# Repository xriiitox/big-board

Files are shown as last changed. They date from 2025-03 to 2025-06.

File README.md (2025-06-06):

# big-board

I wanted to make this keyboard to gain KiCAD experience and work on a larger project that included more difficult CAD.  
This was the first large-scale PCB I've worked on.  
The routing was very difficult, and it forced me to learn how to use vias correctly lol  

Personally, I don't really need much from a keyboard, so I tried to keep it simple with a minimalist design:
* No RGB
* No OLED Display
* No Rotary Encoders

Images: 

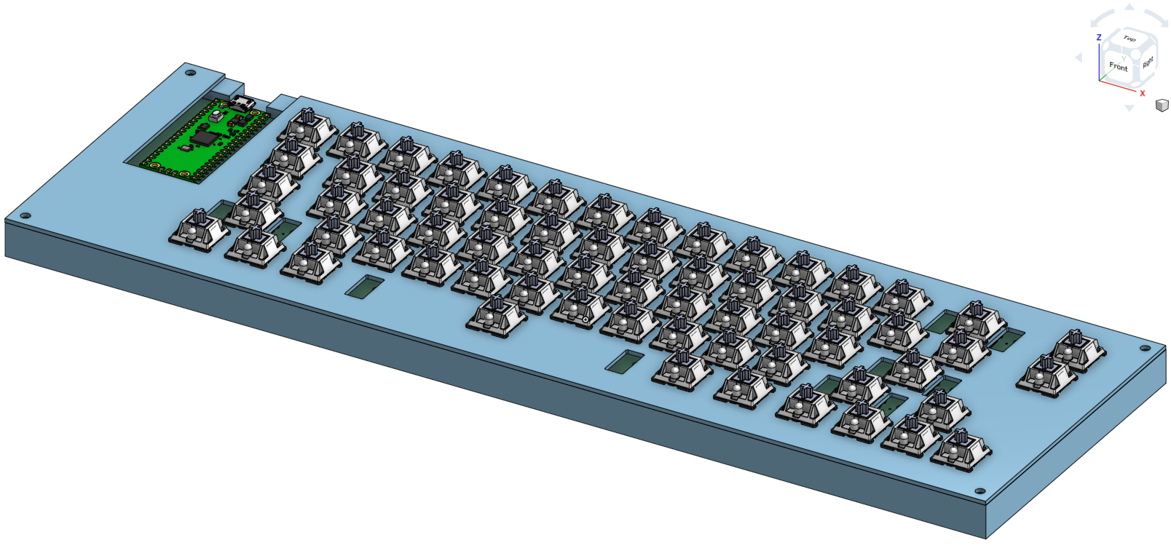
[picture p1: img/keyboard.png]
keyboard

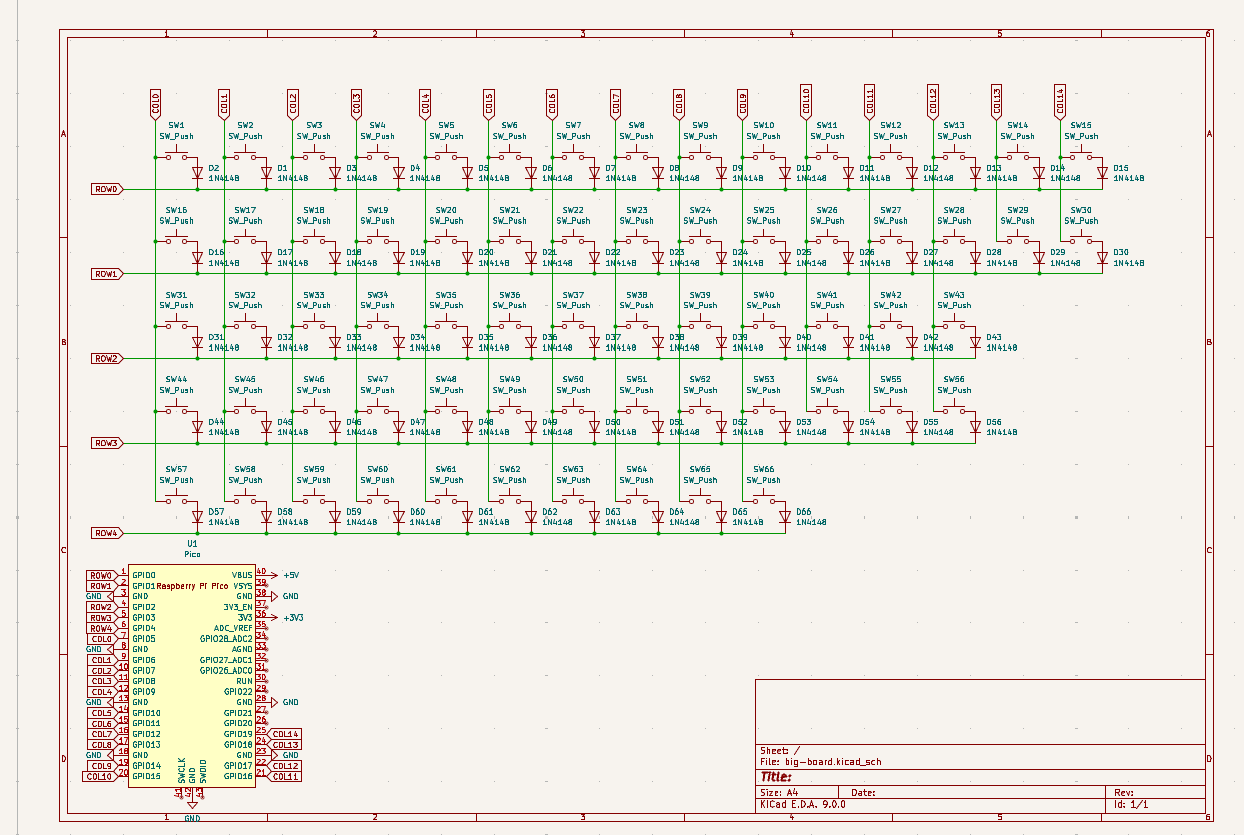
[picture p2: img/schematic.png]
schematic

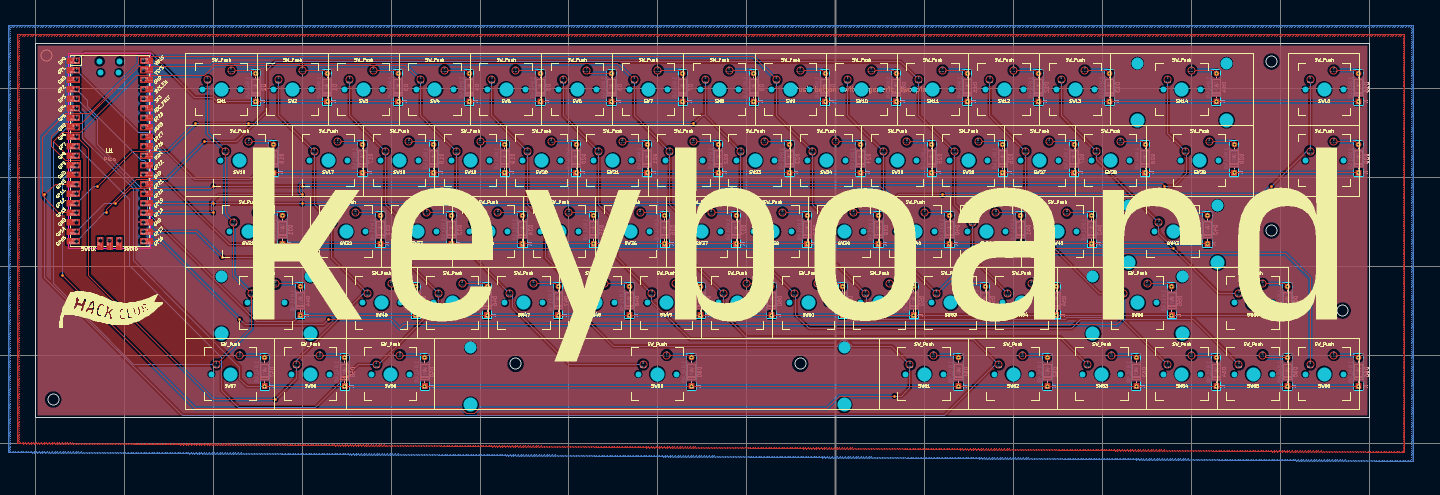
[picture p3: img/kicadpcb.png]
pcb


BOM:  
| Item | Quantity | $/item | Total (inc. shipping) | Link |
| --- | --- | --- | --- | ---- |
| 1N4148 | 70 | 0.0292 | ~$10.50 | https://www.digikey.com/en/products/detail/onsemi/1N4148/458603 |
| Switches | 80 | 2.30 | ~$23.40 | https://milktooth.com/products/switches/milky-yellow-pro |
| Keycaps  | 1 | 0.99 | ~$1.06  | https://www.aliexpress.us/item/3256807135386098.html  |
| Stabs | 1 set | 16.99  | $16.99 | https://www.amazon.com/DUROCK-Stabilizers-Stabilizer-Pre-Clipped-Mechanical/dp/B0B2RTQ1C2 |
| M3 Screws| 1 box | 9.99 | $9.99 | https://www.amazon.com/Assortment-Stainless-Replacement-Machine-Fastener/dp/B0BMQFHDBH |
| Orpheus Pico | 1 | 0.00 | 0.00 | N/A

PCB:
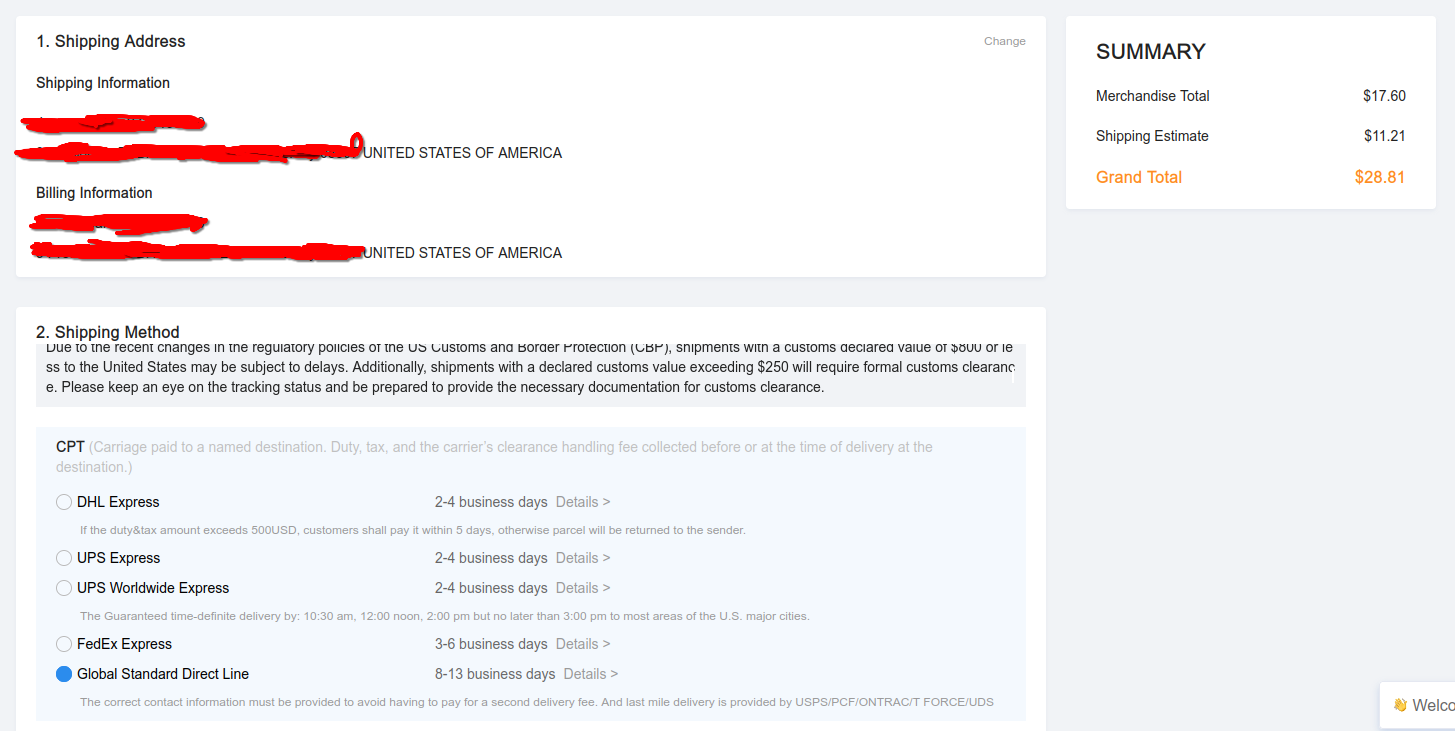
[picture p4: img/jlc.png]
jlcpcb


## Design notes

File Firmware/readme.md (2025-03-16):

# big_board

big_board

*A short description of the keyboard/project*

* Keyboard Maintainer: [Josh Baron](https://github.com/xriiitox)
* Hardware Supported: *The PCBs, controllers supported*
* Hardware Availability: *Links to where you can find this hardware*

Make example for this keyboard (after setting up your build environment):

    make big_board:default

Flashing example for this keyboard:

    make big_board:default:flash

See the [build environment setup](https://docs.qmk.fm/#/getting_started_build_tools) and the [make instructions](https://docs.qmk.fm/#/getting_started_make_guide) for more information. Brand new to QMK? Start with our [Complete Newbs Guide](https://docs.qmk.fm/#/newbs).

## Bootloader

Enter the bootloader in 3 ways:

* **Bootmagic reset**: Hold down the key at (0,0) in the matrix (usually the top left key or Escape) and plug in the keyboard
* **Physical reset button**: Briefly press the button on the back of the PCB - some may have pads you must short instead
* **Keycode in layout**: Press the key mapped to `QK_BOOT` if it is available

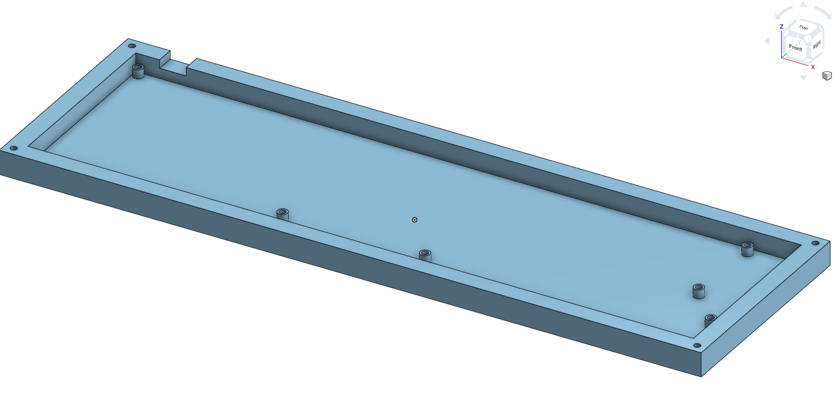
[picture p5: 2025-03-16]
img/lower-case.png

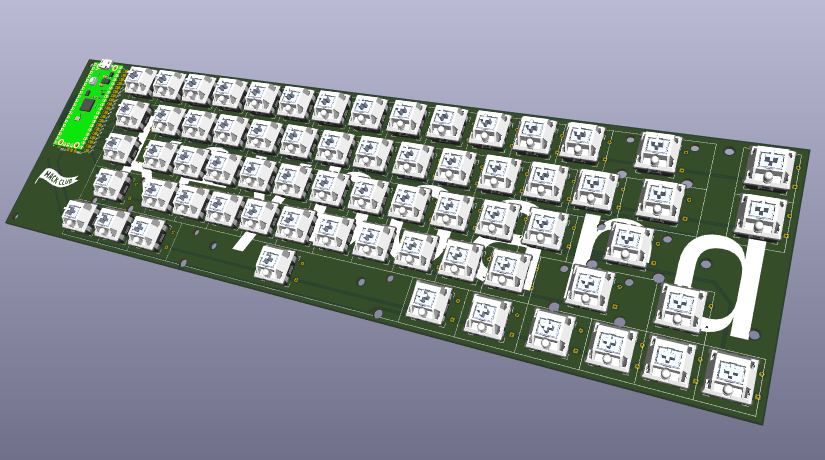
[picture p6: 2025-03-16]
img/3d.png

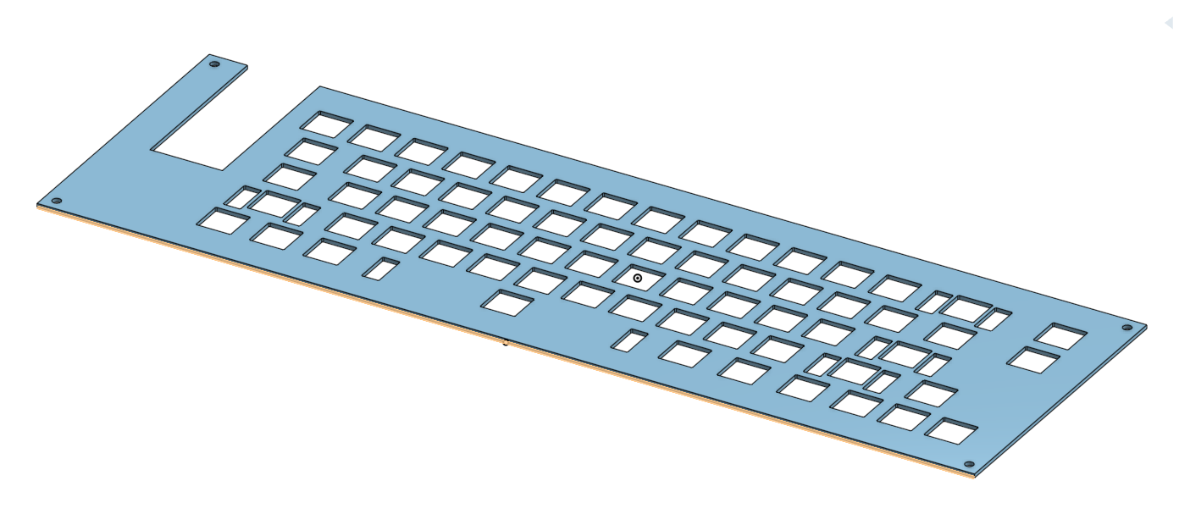
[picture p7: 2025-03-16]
img/upper-case.png

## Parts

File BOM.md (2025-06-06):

# big_board

| Item | Quantity | $/item | Total (inc. shipping) |
| --- | --- | --- | --- |
| 1N4148 | 70 | 0.0292 | ~$10.50 |
| Switches | 80 | 2.30 | ~$23.40 |
| Keycaps  | 1 | 0.99 | ~$1.06  |
| Stabs | 1 set | 16.99  | $16.99 |
| M3 Screws| 1 box | 9.99 | $9.99 |

also, orpheus pico fulfilled by HQ  

Switches are sold in packs of 10 from milktooth  
The keycaps are from Aliexpress, which is why they are so cheap.

PCB BOM is shown in the BOM folder  

Keycaps: https://www.aliexpress.us/item/3256807135386098.html  
Switches: https://milktooth.com/products/switches/milky-yellow-pro  
Diodes: https://www.digikey.com/en/products/detail/onsemi/1N4148/458603  
Stabilizers: https://www.amazon.com/DUROCK-Stabilizers-Stabilizer-Pre-Clipped-Mechanical/dp/B0B2RTQ1C2 (free shipping)  
M3 screws + nuts if needed: https://www.amazon.com/Assortment-Stainless-Replacement-Machine-Fastener/dp/B0BMQFHDBH (free shipping)

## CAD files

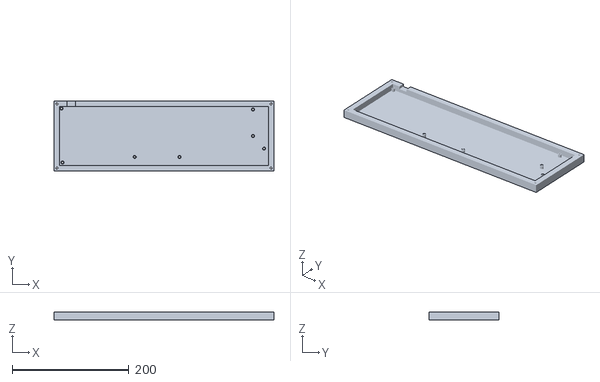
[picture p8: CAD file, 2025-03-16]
Production/Case/Assembly 1 - Part 1.stl
377.2 x 120.0 x 13.0

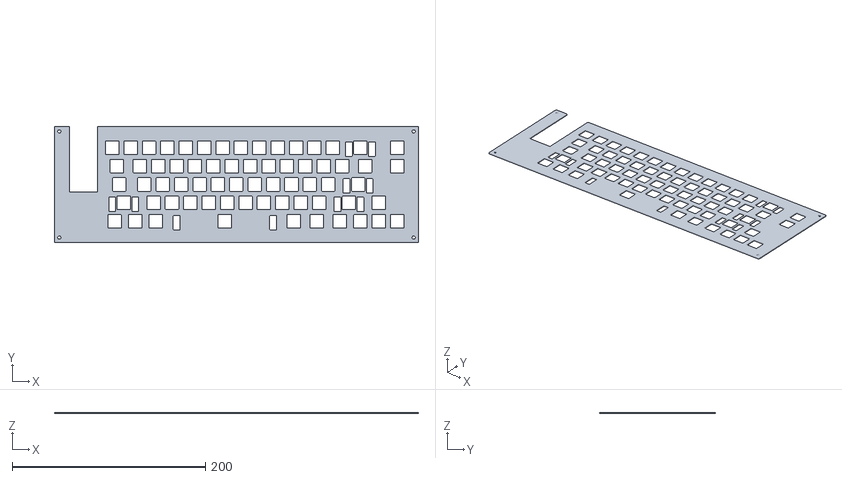
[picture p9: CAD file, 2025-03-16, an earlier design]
Production/Case/Assembly 1 - Part 1 (1).stl
377.2 x 120.0 x 1.50

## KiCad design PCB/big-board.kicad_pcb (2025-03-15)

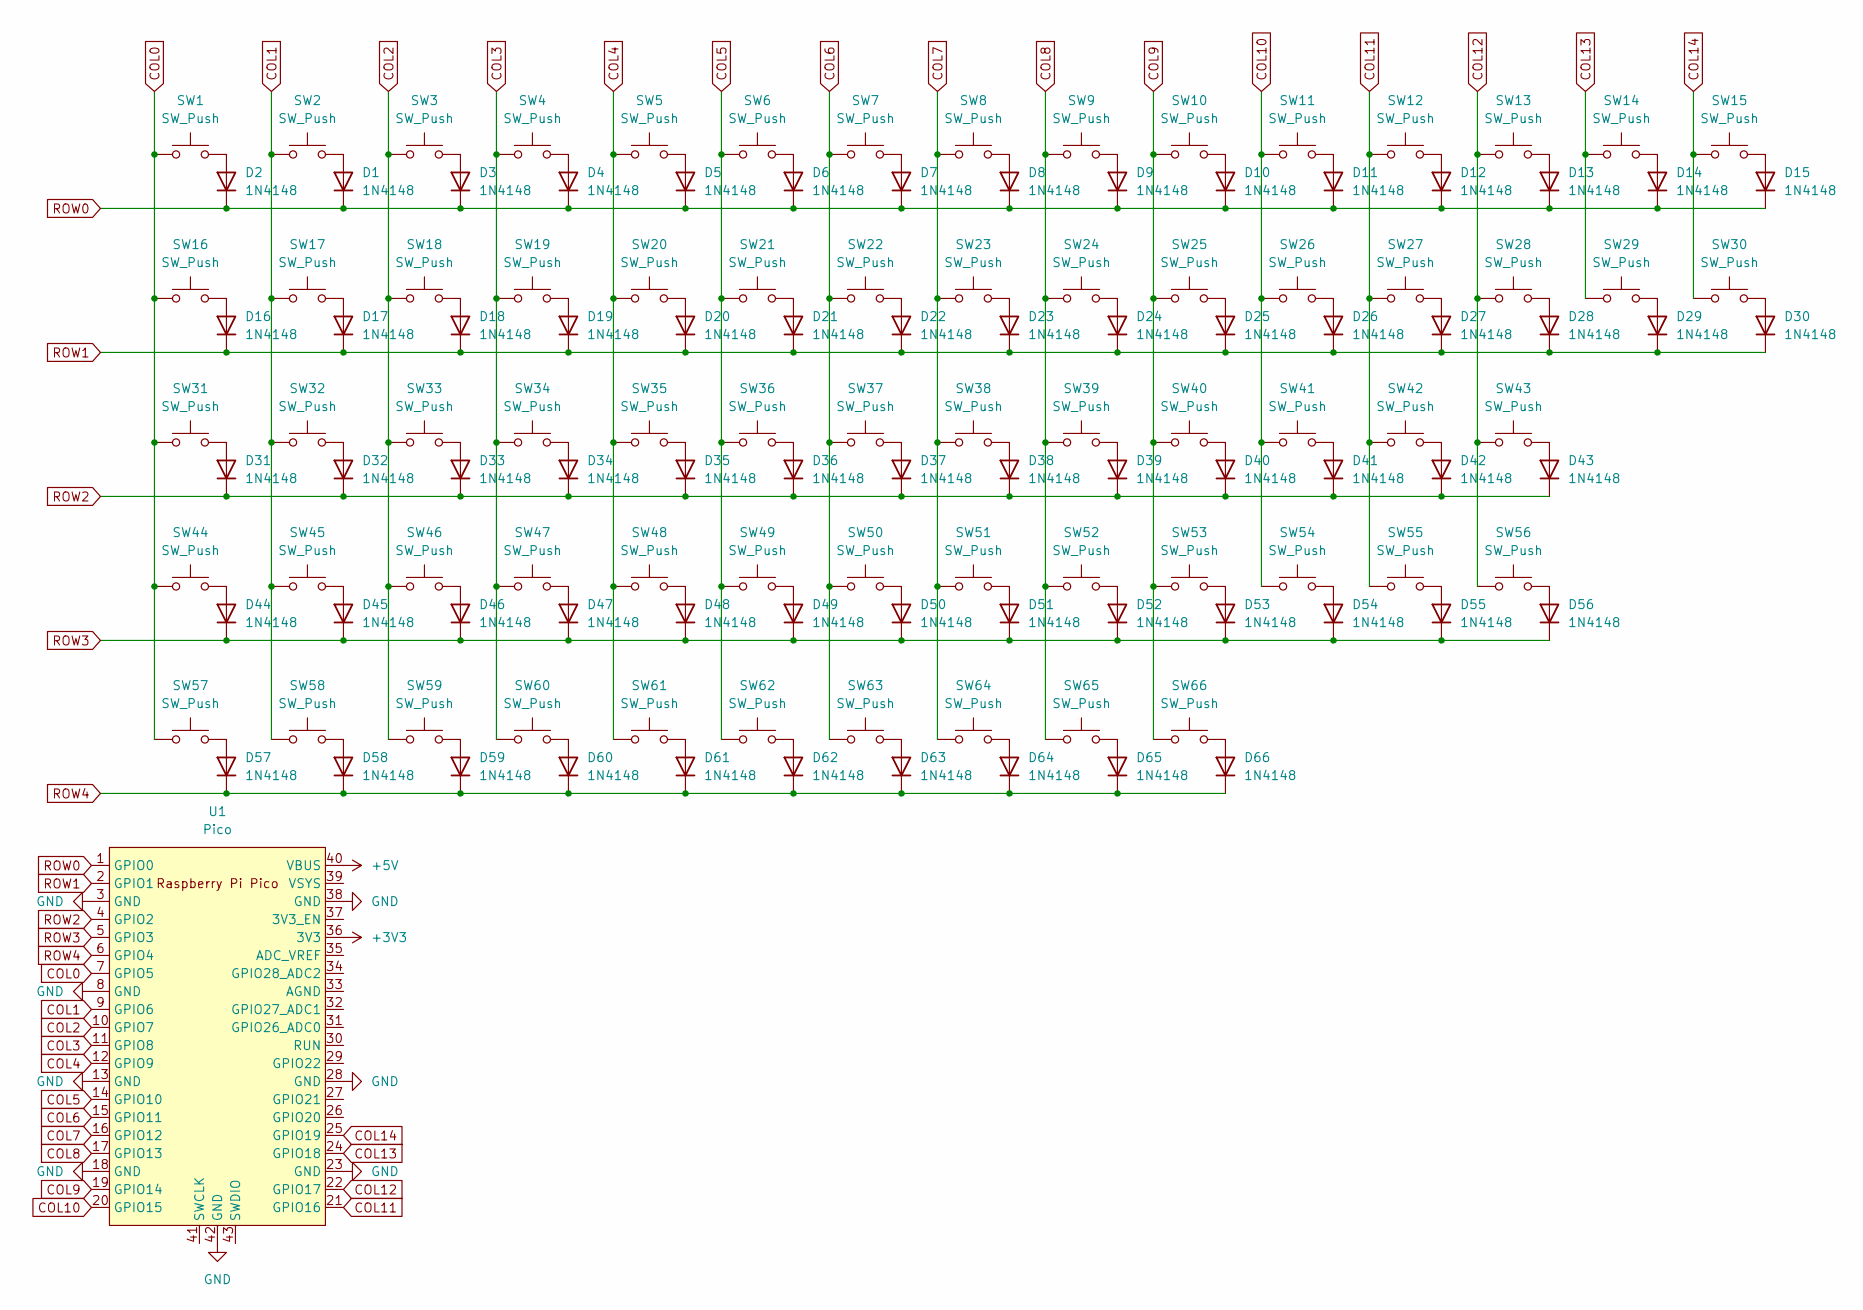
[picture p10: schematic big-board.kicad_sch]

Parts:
D1, D2, D3, D4, D5, D6, D7, D8, D9, D10, D11, D12, D13, D14, D15, D16, D17, D18, D19, D20, D21, D22, D23, D24, D25, D26, D27, D28, D29, D30, D31, D32, D33, D34, D35, D36, D37, D38, D39, D40, D41, D42, D43, D44, D45, D46, D47, D48, D49, D50, D51, D52, D53, D54, D55, D56, D57, D58, D59, D60, D61, D62, D63, D64, D65, D66: 1N4148; D_DO-35_SOD27_P7.62mm_Horizontal
SW1, SW2, SW3, SW4, SW5, SW6, SW7, SW8, SW9, SW10, SW11, SW12, SW13, SW15, SW17, SW18, SW19, SW20, SW21, SW22, SW23, SW24, SW25, SW26, SW27, SW28, SW30, SW32, SW33, SW34, SW35, SW36, SW37, SW38, SW39, SW40, SW41, SW42, SW45, SW46, SW47, SW48, SW49, SW50, SW51, SW52, SW53, SW54, SW56, SW58, SW64, SW65, SW66: SW_Push; MX-Solderable-1U
SW14: SW_Push; MX-Solderable-2U
SW16, SW29: SW_Push; MX-Solderable-1.5U
SW31: SW_Push; MX-Solderable-1.75U
SW43, SW44, SW55: SW_Push; MX-Solderable-2.25U
SW57, SW59, SW61, SW62, SW63: SW_Push; MX-Solderable-1.25U
SW60: SW_Push; MX-Solderable-6.25U
U1: Pico; RPi_Pico_SMD_TH

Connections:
+3V3: U1.36 (3V3)
+5V: U1.40 (VBUS)
COL0: SW1.1, SW16.1, SW31.1, SW44.1, SW57.1, U1.7 (GPIO5)
COL1: SW2.1, SW17.1, SW32.1, SW45.1, SW58.1, U1.9 (GPIO6)
COL2: SW3.1, SW18.1, SW33.1, SW46.1, SW59.1, U1.10 (GPIO7)
COL3: SW4.1, SW19.1, SW34.1, SW47.1, SW60.1, U1.11 (GPIO8)
COL4: SW5.1, SW20.1, SW35.1, SW48.1, SW61.1, U1.12 (GPIO9)
COL5: SW6.1, SW21.1, SW36.1, SW49.1, SW62.1, U1.14 (GPIO10)
COL6: SW7.1, SW22.1, SW37.1, SW50.1, SW63.1, U1.15 (GPIO11)
COL7: SW8.1, SW23.1, SW38.1, SW51.1, SW64.1, U1.16 (GPIO12)
COL8: SW9.1, SW24.1, SW39.1, SW52.1, SW65.1, U1.17 (GPIO13)
COL9: SW10.1, SW25.1, SW40.1, SW53.1, SW66.1, U1.19 (GPIO14)
COL10: SW11.1, SW26.1, SW41.1, SW54.1, U1.20 (GPIO15)
COL11: SW12.1, SW27.1, SW42.1, SW55.1, U1.21 (GPIO16)
COL12: SW13.1, SW28.1, SW43.1, SW56.1, U1.22 (GPIO17)
COL13: SW14.1, SW29.1, U1.24 (GPIO18)
COL14: SW15.1, SW30.1, U1.25 (GPIO19)
GND: U1.3 (GND), U1.8 (GND), U1.13 (GND), U1.18 (GND), U1.23 (GND), U1.28 (GND), U1.38 (GND), U1.42 (GND)
unnamed: D1.2 (A), SW2.2
unnamed: D2.2 (A), SW1.2
unnamed: D3.2 (A), SW3.2
unnamed: D4.2 (A), SW4.2
unnamed: D5.2 (A), SW5.2
unnamed: D6.2 (A), SW6.2
unnamed: D7.2 (A), SW7.2
unnamed: D8.2 (A), SW8.2
unnamed: D9.2 (A), SW9.2
unnamed: D10.2 (A), SW10.2
unnamed: D11.2 (A), SW11.2
unnamed: D12.2 (A), SW12.2
unnamed: D13.2 (A), SW13.2
unnamed: D14.2 (A), SW14.2
unnamed: D15.2 (A), SW15.2
unnamed: D16.2 (A), SW16.2
unnamed: D17.2 (A), SW17.2
unnamed: D18.2 (A), SW18.2
unnamed: D19.2 (A), SW19.2
unnamed: D20.2 (A), SW20.2
unnamed: D21.2 (A), SW21.2
unnamed: D22.2 (A), SW22.2
unnamed: D23.2 (A), SW23.2
unnamed: D24.2 (A), SW24.2
unnamed: D25.2 (A), SW25.2
unnamed: D26.2 (A), SW26.2
unnamed: D27.2 (A), SW27.2
unnamed: D28.2 (A), SW28.2
unnamed: D29.2 (A), SW29.2
unnamed: D30.2 (A), SW30.2
unnamed: D31.2 (A), SW31.2
unnamed: D32.2 (A), SW32.2
unnamed: D33.2 (A), SW33.2
unnamed: D34.2 (A), SW34.2
unnamed: D35.2 (A), SW35.2
unnamed: D36.2 (A), SW36.2
unnamed: D37.2 (A), SW37.2
unnamed: D38.2 (A), SW38.2
unnamed: D39.2 (A), SW39.2
unnamed: D40.2 (A), SW40.2
unnamed: D41.2 (A), SW41.2
unnamed: D42.2 (A), SW42.2
unnamed: D43.2 (A), SW43.2
unnamed: D44.2 (A), SW44.2
unnamed: D45.2 (A), SW45.2
unnamed: D46.2 (A), SW46.2
unnamed: D47.2 (A), SW47.2
unnamed: D48.2 (A), SW48.2
unnamed: D49.2 (A), SW49.2
unnamed: D50.2 (A), SW50.2
unnamed: D51.2 (A), SW51.2
unnamed: D52.2 (A), SW52.2
unnamed: D53.2 (A), SW53.2
unnamed: D54.2 (A), SW54.2
unnamed: D55.2 (A), SW55.2
unnamed: D56.2 (A), SW56.2
unnamed: D57.2 (A), SW57.2
unnamed: D58.2 (A), SW58.2
unnamed: D59.2 (A), SW59.2
unnamed: D60.2 (A), SW60.2
unnamed: D61.2 (A), SW61.2
unnamed: D62.2 (A), SW62.2
unnamed: D63.2 (A), SW63.2
unnamed: D64.2 (A), SW64.2
unnamed: D65.2 (A), SW65.2
unnamed: D66.2 (A), SW66.2
ROW0: D1.1 (K), D2.1 (K), D3.1 (K), D4.1 (K), D5.1 (K), D6.1 (K), D7.1 (K), D8.1 (K), D9.1 (K), D10.1 (K), D11.1 (K), D12.1 (K), D13.1 (K), D14.1 (K), D15.1 (K), U1.1 (GPIO0)
ROW1: D16.1 (K), D17.1 (K), D18.1 (K), D19.1 (K), D20.1 (K), D21.1 (K), D22.1 (K), D23.1 (K), D24.1 (K), D25.1 (K), D26.1 (K), D27.1 (K), D28.1 (K), D29.1 (K), D30.1 (K), U1.2 (GPIO1)
ROW2: D31.1 (K), D32.1 (K), D33.1 (K), D34.1 (K), D35.1 (K), D36.1 (K), D37.1 (K), D38.1 (K), D39.1 (K), D40.1 (K), D41.1 (K), D42.1 (K), D43.1 (K), U1.4 (GPIO2)
ROW3: D44.1 (K), D45.1 (K), D46.1 (K), D47.1 (K), D48.1 (K), D49.1 (K), D50.1 (K), D51.1 (K), D52.1 (K), D53.1 (K), D54.1 (K), D55.1 (K), D56.1 (K), U1.5 (GPIO3)
ROW4: D57.1 (K), D58.1 (K), D59.1 (K), D60.1 (K), D61.1 (K), D62.1 (K), D63.1 (K), D64.1 (K), D65.1 (K), D66.1 (K), U1.6 (GPIO4)

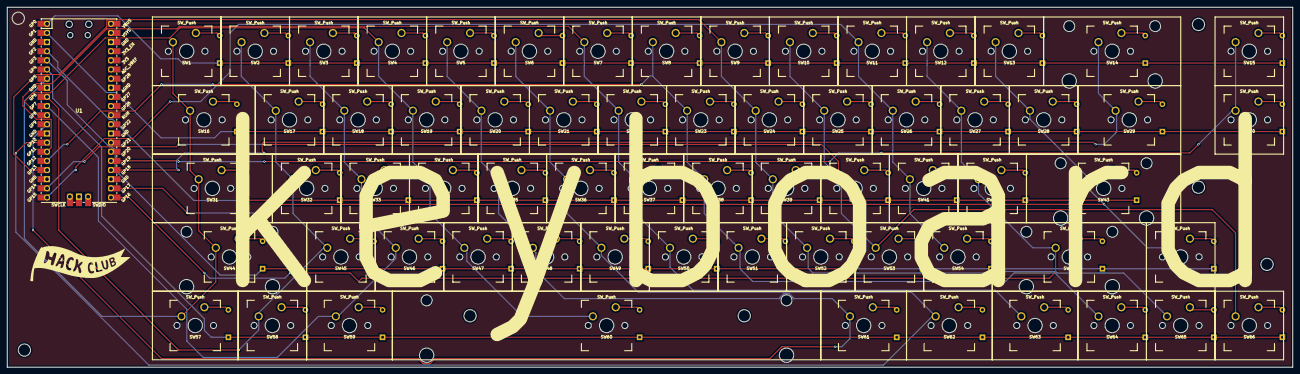
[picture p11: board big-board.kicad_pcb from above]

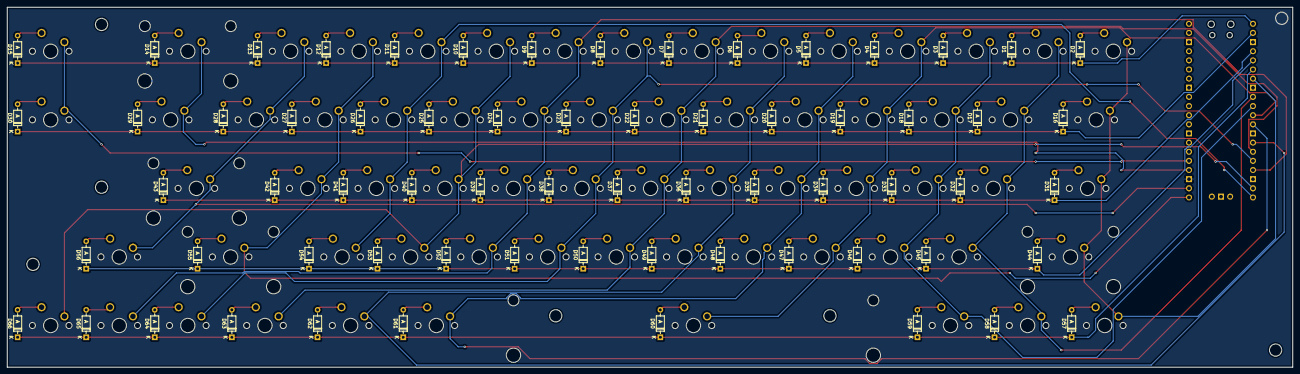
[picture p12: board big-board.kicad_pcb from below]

Board: 2 copper layers, 357.2 x 100.0 mm, 133 parts (66 on the bottom side), 86 nets.

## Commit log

2025-02-21 start routing
    [big-board.kicad_pcb, big-board.kicad_sch]
2025-02-21 keep routing
    [big-board.kicad_pcb]
2025-02-28 more pcb routing
    [big-board.kicad_pcb, big-board.kicad_sch]
2025-03-01 finish pcb
    [big-board.kicad_pcb]
2025-03-03 silkscreen stuff
    [big-board.kicad_pcb, big-board.kicad_sch]
2025-03-15 fix pcb and generate 3d model
    [big-board.kicad_pcb, big-board.kicad_sch]
2025-03-16 separate folders and add CAD
    [Assembly 1 - Part 1 (1).stl, Assembly 1 - Part 1.stl, big-board.kicad_pcb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]
2025-03-16 reorganize, add BOM, add gerbers
    [Assembly 1 - Part 1 (1).stl, Assembly 1 - Part 1.stl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]
2025-06-06 fix BOM.md
